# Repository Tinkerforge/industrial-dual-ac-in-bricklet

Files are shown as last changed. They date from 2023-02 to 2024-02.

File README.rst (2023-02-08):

Industrial Dual AC In Bricklet
==============================

**This Bricklet is currently in development.**

This repository contains the firmware source code and the hardware design
files. The documentation generator configs can be found at
https://github.com/Tinkerforge/generators

Repository Content
------------------

software/:
 * examples/: Examples for all supported languages
 * build/: Compiled files
 * src/: Source code of firmware
 * Makefile: Makefile to build project

hardware/:
 * Contains KiCad project files and additionally schematics as PDF

datasheets/:
 * Contains datasheets for sensors and complex ICs that are used

Hardware
--------

The hardware is designed with the open source EDA Suite KiCad
(http://www.kicad.org). Before you are able to open the files,
you have to install the Tinkerforge kicad-libraries
(https://github.com/Tinkerforge/kicad-libraries). You can either clone
them directly in hardware/ or clone them in a separate folder and
symlink them into hardware/
(ln -s kicad_path/kicad-libraries project_path/hardware). After that you
can open the .pro file in hardware/ with KiCad and from there view and
modify the schematics and the PCB layout.

Software
--------

If you want to do your own Brick/Bricklet firmware development we highly
recommend that you use our build environment setup script and read the
tutorial (https://www.tinkerforge.com/en/doc/Tutorials/Tutorial_Build_Environment/Tutorial.html).

To compile the C code we recommend you to install the newest GNU Arm Embedded
Toolchain (https://launchpad.net/gcc-arm-embedded/+download).
You also need to install bricklib2 (https://github.com/Tinkerforge/bricklib2).

You can either clone it directly in software/src/ or clone it in a
separate folder and symlink it into software/src/
(ln -s bricklib_path/bricklib2 project_path/software/src/). Finally make sure to
have CMake installed (http://www.cmake.org/cmake/resources/software.html).

After that you can build the firmware by invoking make in software/.
The firmware (.zbin) can then be found in software/build/ and uploaded
with brickv (click button "Flashing" on start screen).

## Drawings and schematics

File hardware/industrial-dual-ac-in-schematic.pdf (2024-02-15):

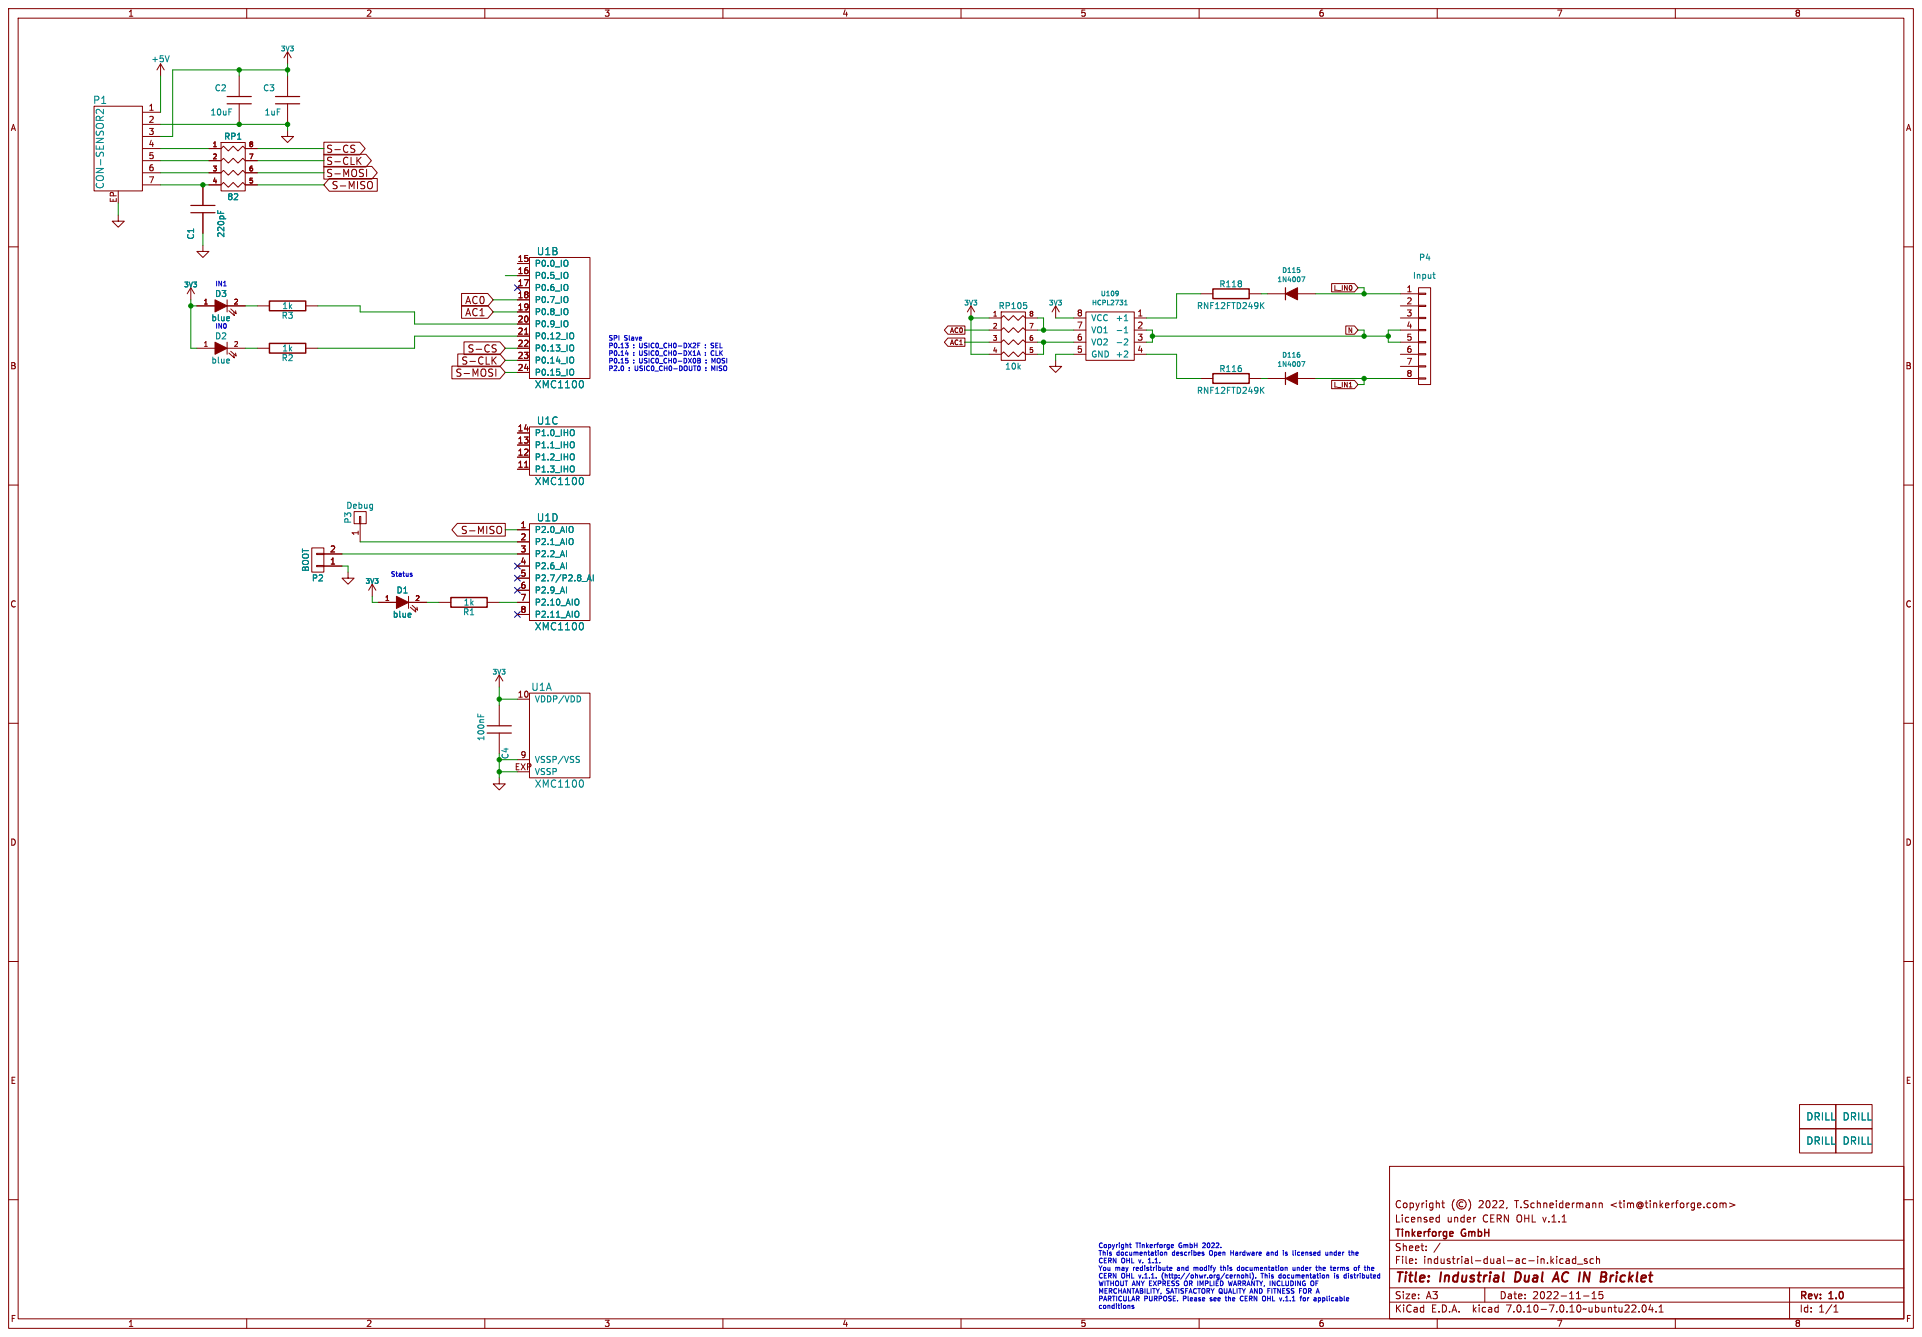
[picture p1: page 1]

Id: 1/1 Title: Industrial Dual AC IN Bricklet File: industrial-dual-ac-in.kicad_sch Sheet: / Tinkerforge GmbH

PARTICULAR PURPOSE. Please see the CERN OHL v.1.1 for applicable
conditions

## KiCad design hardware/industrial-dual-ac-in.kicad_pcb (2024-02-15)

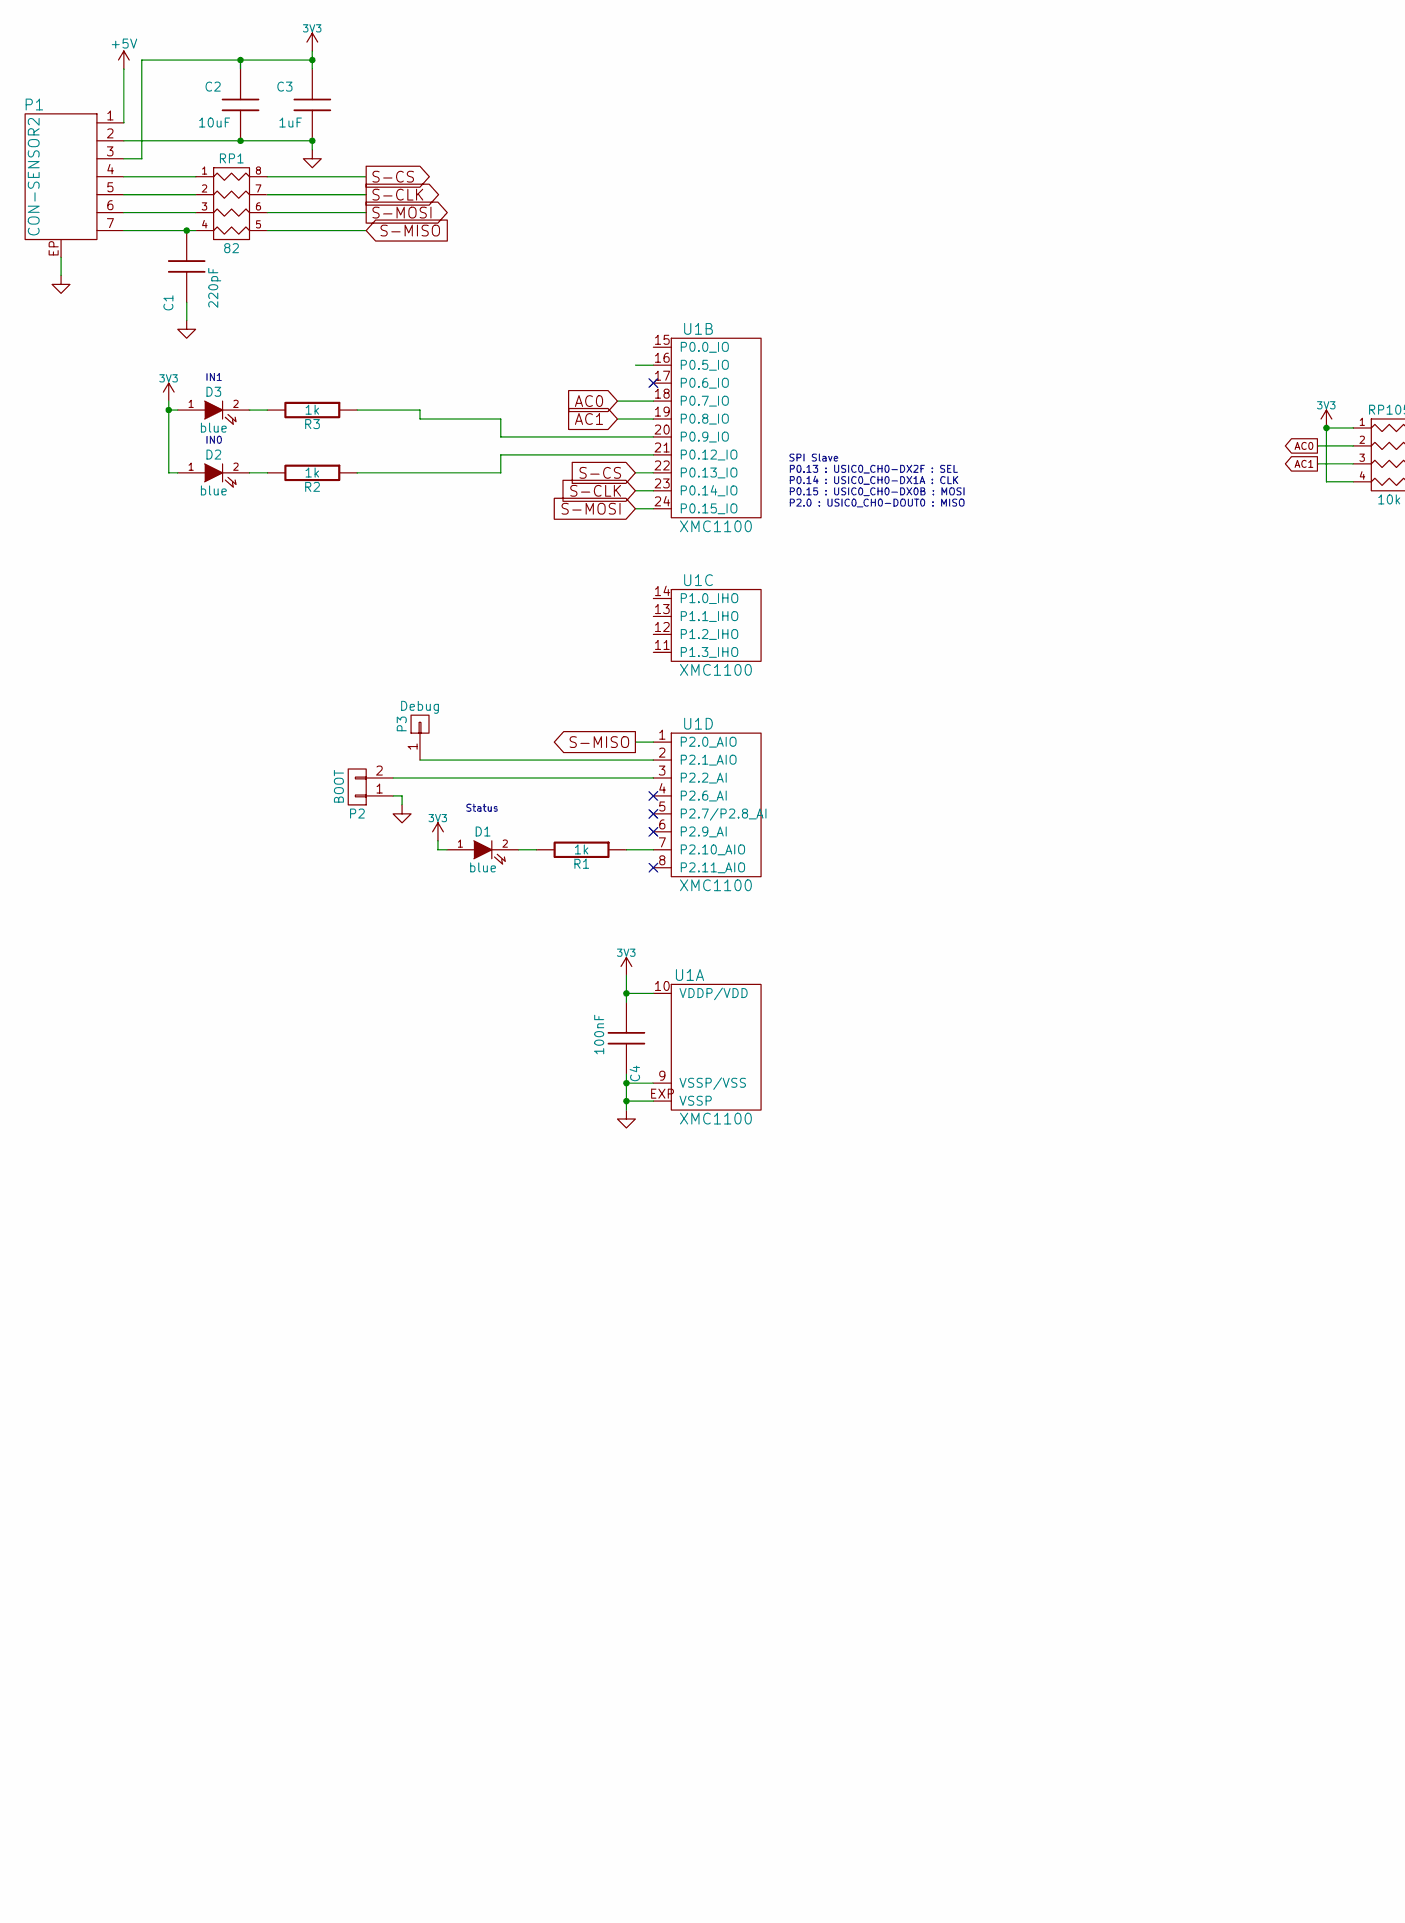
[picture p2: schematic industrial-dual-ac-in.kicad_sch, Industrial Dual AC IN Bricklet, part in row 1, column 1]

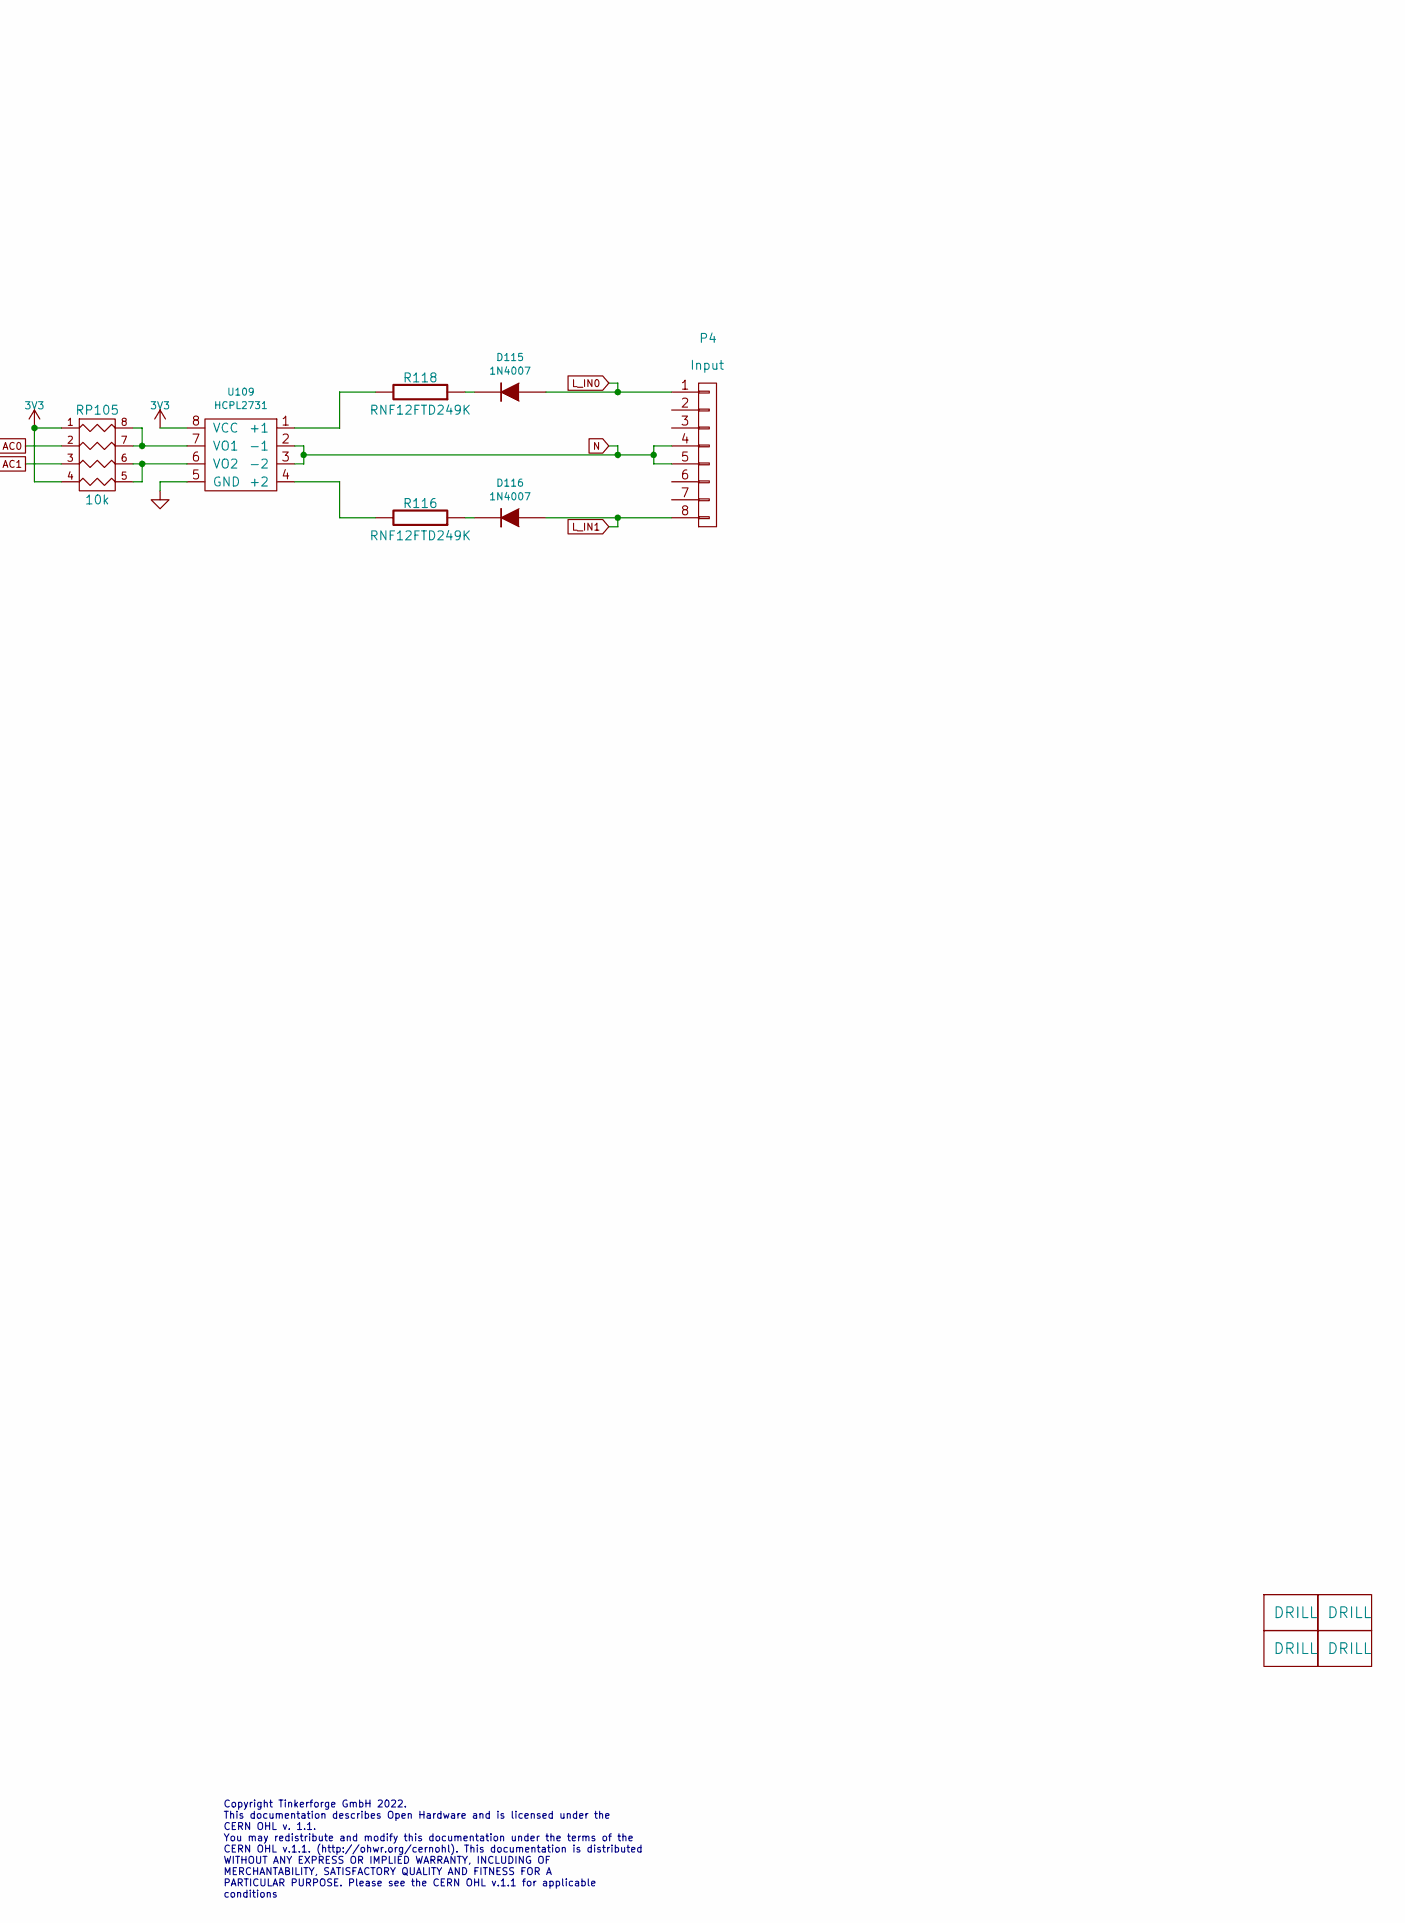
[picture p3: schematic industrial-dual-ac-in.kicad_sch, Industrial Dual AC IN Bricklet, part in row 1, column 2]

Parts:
C1: 220pF; C0402F
C2: 10uF; C0805E
C3: 1uF; C0603F
C4: 100nF; C0603F
D1, D2, D3: blue; D0603E
D115, D116: 1N4007; DO-41
Drill1, Drill2, Drill3, Drill4: DRILL; DRILL_NP
P1: CON-SENSOR2
P2: BOOT; SolderJumper
P3: Debug; DEBUG_PAD
P4: Input; OQ_8P_230V
R1, R2, R3: 1k; R0603F
R116, R118: RNF12FTD249K; RNF12-2
RP1: 82; 4X0402
RP105: 10k; 4X0603
U1: XMC1100; QFN24-4x4mm-0.5mm
U109: HCPL2731; DIP-8

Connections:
3V3: C2.2, C3.2, C4.1, D1.1 (A), D2.1 (A), D3.1 (A), P1.3, RP105.1, RP105.4, U1.10 (VDDP/VDD), U109.8 (VCC)
+5V: P1.1
AC0: RP105.2, U1.18 (P0.7_IO)
AC1: RP105.3, U1.19 (P0.8_IO)
GND: C1.1, C2.1, C3.1, C4.2, P1.2, P1.EP, P2.1, U1.9 (VSSP/VSS), U1.EXP (VSSP), U109.5 (GND)
L_IN0: D115.1 (A), P4.1
L_IN1: D116.1 (A), P4.8
N: P4.4, P4.5, U109.2 (-1), U109.3 (-2)
unnamed: D1.2 (K), R1.2
unnamed: D2.2 (K), R2.2
unnamed: D3.2 (K), R3.2
unnamed: D115.2 (K), R118.1
unnamed: D116.2 (K), R116.1
unnamed: P2.2, U1.3 (P2.2_AI)
unnamed: P3.1, U1.2 (P2.1_AIO)
unnamed: P1.4, RP1.1
unnamed: P1.5, RP1.2
unnamed: P1.6, RP1.3
unnamed: C1.2, P1.7, RP1.4
unnamed: RP105.7 (R2), RP105.8 (R1), U109.7 (VO1)
unnamed: RP105.5 (R4), RP105.6 (R3), U109.6 (VO2)
unnamed: R3.1, U1.20 (P0.9_IO)
unnamed: R2.1, U1.21 (P0.12_IO)
unnamed: R1.1, U1.7 (P2.10_AIO)
unnamed: R118.2, U109.1 (+1)
unnamed: R116.2, U109.4 (+2)
S-CLK: RP1.7 (R2), U1.23 (P0.14_IO)
S-CS: RP1.8 (R1), U1.22 (P0.13_IO)
S-MISO: RP1.5 (R4), U1.1 (P2.0_AIO)
S-MOSI: RP1.6 (R3), U1.24 (P0.15_IO)

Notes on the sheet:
SPI Slave P0.13 : USIC0_CH0-DX2F : SEL P0.14 : USIC0_CH0-DX1A : CLK P0.15 : USIC0_CH0-DX0B : MOSI P2.0 : USIC0_CH0-DOUT0 : MISO
Status
IN0
IN1
Copyright Tinkerforge GmbH 2022. This documentation describes Open Hardware and is licensed under the CERN OHL v. 1.1. You may redistribute and modify this documentation under the terms of the CERN OHL v.1.1. (http://ohwr.org/cernohl). This documentation is distributed WITHOUT ANY EXPRESS OR IMPLIE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

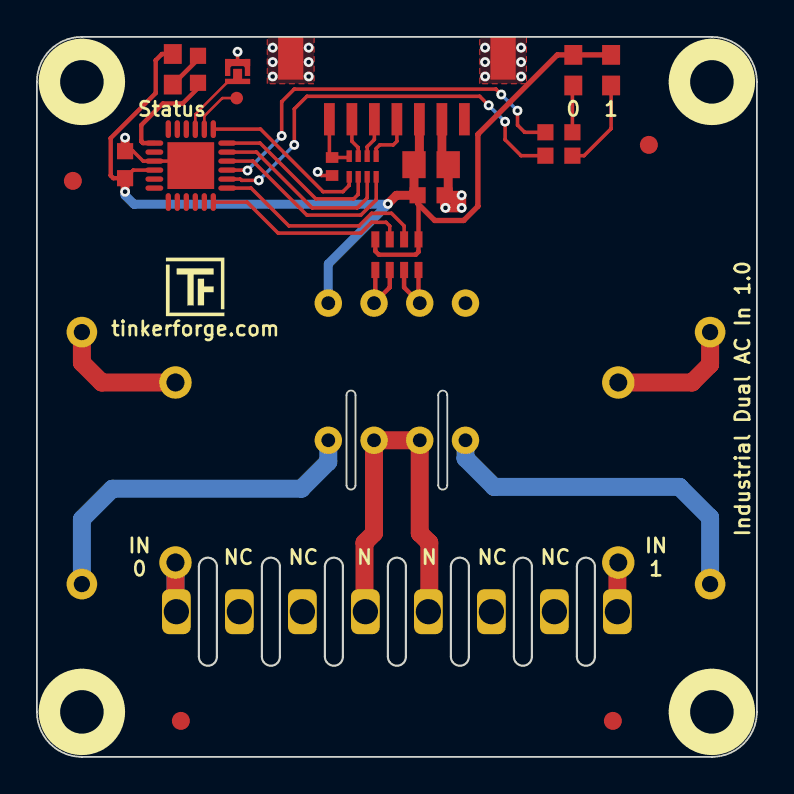
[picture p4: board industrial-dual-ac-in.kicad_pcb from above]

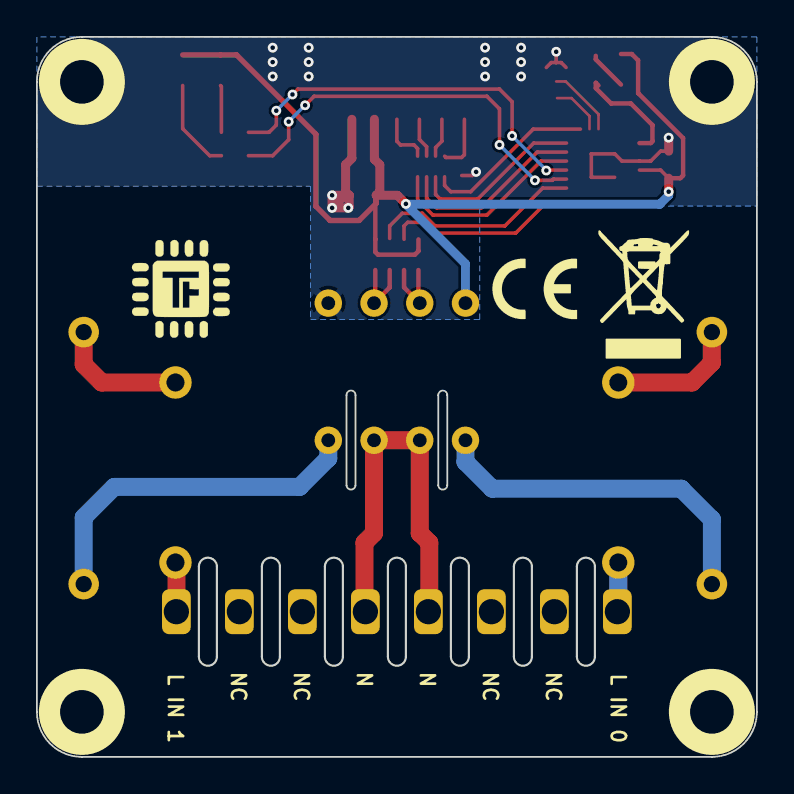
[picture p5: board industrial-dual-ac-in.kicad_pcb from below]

Board: 2 copper layers, 40.0 x 40.0 mm, 32 parts (2 on the bottom side), 29 nets.

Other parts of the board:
Fiducial_Mark: VAL**; Fiducial_Mark
Fiducial_Mark#2, Fiducial_Mark#3, Fiducial_Mark#4: VAL**; Fiducial_Mark
VAL: WEEE_7mm
VAL#2: CE_5mm

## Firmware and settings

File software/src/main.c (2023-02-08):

/* industrial-dual-ac-in-bricklet
 * Copyright (C) 2023 Olaf Lüke <olaf@tinkerfoe.com>
 *
 * main.c: Initialization for Industrial Dual AC In Bricklet
 *
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
 * You should have received a copy of the GNU Lesser General Public
 * License along with this library; if not, write to the
 * Free Software Foundation, Inc., 59 Temple Place - Suite 330,
 * Boston, MA 02111-1307, USA.
 */

#include <stdio.h>
#include <stdbool.h>

#include "configs/config.h"

#include "bricklib2/bootloader/bootloader.h"
#include "bricklib2/hal/system_timer/system_timer.h"
#include "bricklib2/logging/logging.h"
#include "communication.h"

#include "ac_in.h"

int main(void) {
	logging_init();
	logd("Start Industrial Dual AC In Bricklet\n\r");

	communication_init();
	ac_in_init();

	while(true) {
		bootloader_tick();
		communication_tick();
		ac_in_tick();
	}
}

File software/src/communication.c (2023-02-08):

/* industrial-dual-ac-in-bricklet
 * Copyright (C) 2023 Olaf Lüke <olaf@tinkerfoe.com>
 *
 * communication.c: TFP protocol message handling
 *
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
 * You should have received a copy of the GNU Lesser General Public
 * License along with this library; if not, write to the
 * Free Software Foundation, Inc., 59 Temple Place - Suite 330,
 * Boston, MA 02111-1307, USA.
 */

#include "communication.h"

#include "bricklib2/hal/system_timer/system_timer.h"
#include "bricklib2/utility/communication_callback.h"
#include "bricklib2/protocols/tfp/tfp.h"

#include "ac_in.h"

BootloaderHandleMessageResponse handle_message(const void *message, void *response) {
	switch(tfp_get_fid_from_message(message)) {
		case FID_GET_VALUE: return get_value(message, response);
		case FID_SET_VALUE_CALLBACK_CONFIGURATION: return set_value_callback_configuration(message);
		case FID_GET_VALUE_CALLBACK_CONFIGURATION: return get_value_callback_configuration(message, response);
		case FID_SET_ALL_VALUE_CALLBACK_CONFIGURATION: return set_all_value_callback_configuration(message);
		case FID_GET_ALL_VALUE_CALLBACK_CONFIGURATION: return get_all_value_callback_configuration(message, response);
		case FID_SET_CHANNEL_LED_CONFIG: return set_channel_led_config(message);
		case FID_GET_CHANNEL_LED_CONFIG: return get_channel_led_config(message, response);
		default: return HANDLE_MESSAGE_RESPONSE_NOT_SUPPORTED;
	}
}


BootloaderHandleMessageResponse get_value(const GetValue *data, GetValue_Response *response) {
	response->header.length = sizeof(GetValue_Response);
	response->value[0]      = ac_in.value[0] | (ac_in.value[1] << 1);

	return HANDLE_MESSAGE_RESPONSE_NEW_MESSAGE;
}

BootloaderHandleMessageResponse set_value_callback_configuration(const SetValueCallbackConfiguration *data) {
	if(data->channel >= AC_IN_CHANNEL_NUM) {
		return HANDLE_MESSAGE_RESPONSE_INVALID_PARAMETER;
	}	

	ac_in.cb_value_period[data->channel]        = data->period;
	ac_in.cb_value_has_to_change[data->channel] = data->value_has_to_change;
	ac_in.cb_value_last_value[data->channel]    = ac_in.value[data->channel];
	ac_in.cb_value_last_time[data->channel]     = 0;

	return HANDLE_MESSAGE_RESPONSE_EMPTY;
}

BootloaderHandleMessageResponse get_value_callback_configuration(const GetValueCallbackConfiguration *data, GetValueCallbackConfiguration_Response *response) {
	if(data->channel >= AC_IN_CHANNEL_NUM) {
		return HANDLE_MESSAGE_RESPONSE_INVALID_PARAMETER;
	}

	response->header.length = sizeof(GetValueCallbackConfiguration_Response);
	response->period              = ac_in.cb_value_period[data->channel];
	response->value_has_to_change = ac_in.cb_value_has_to_change[data->channel];

	return HANDLE_MESSAGE_RESPONSE_NEW_MESSAGE;
}

BootloaderHandleMessageResponse set_all_value_callback_configuration(const SetAllValueCallbackConfiguration *data) {
	ac_in.cb_all_period        = data->period;
	ac_in.cb_all_has_to_change = data->value_has_to_change;
	ac_in.cb_all_last_value    = ac_in.value[0] | (ac_in.value[1] << 1);
	ac_in.cb_all_last_time     = 0;

	return HANDLE_MESSAGE_RESPONSE_EMPTY;
}

BootloaderHandleMessageResponse get_all_value_callback_configuration(const GetAllValueCallbackConfiguration *data, GetAllValueCallbackConfiguration_Response *response) {
	response->header.length       = sizeof(GetAllValueCallbackConfiguration_Response);
	response->period              = ac_in.cb_all_period;
	response->value_has_to_change = ac_in.cb_all_has_to_change;

	return HANDLE_MESSAGE_RESPONSE_NEW_MESSAGE;
}

BootloaderHandleMessageResponse set_channel_led_config(const SetChannelLEDConfig *data) {
	if(data->channel >= AC_IN_CHANNEL_NUM) {
		return HANDLE_MESSAGE_RESPONSE_INVALID_PARAMETER;
	}

	if(data->config > INDUSTRIAL_DUAL_AC_IN_CHANNEL_LED_CONFIG_SHOW_CHANNEL_STATUS) {
		return HANDLE_MESSAGE_RESPONSE_INVALID_PARAMETER;
	}

	ac_in.led_flicker_state[data->channel].config = data->config;
	if(data->config == INDUSTRIAL_DUAL_AC_IN_CHANNEL_LED_CONFIG_OFF) {
		XMC_GPIO_SetOutputHigh(ac_in_led[data->channel].port, ac_in_led[data->channel].pin);
	} else if(data->config == INDUSTRIAL_DUAL_AC_IN_CHANNEL_LED_CONFIG_ON) {
		XMC_GPIO_SetOutputLow(ac_in_led[data->channel].port, ac_in_led[data->channel].pin);
	}

	return HANDLE_MESSAGE_RESPONSE_EMPTY;
}

BootloaderHandleMessageResponse get_channel_led_config(const GetChannelLEDConfig *data, GetChannelLEDConfig_Response *response) {
	if(data->channel >= AC_IN_CHANNEL_NUM) {
		return HANDLE_MESSAGE_RESPONSE_INVALID_PARAMETER;
	}

	response->header.length = sizeof(GetChannelLEDConfig_Response);
	response->config        = ac_in.led_flicker_state[data->channel].config;

	return HANDLE_MESSAGE_RESPONSE_NEW_MESSAGE;
}




bool handle_value_callback_channel(const uint8_t channel) {
	static bool is_buffered[AC_IN_CHANNEL_NUM] = {false, false};
	static Value_Callback cb[AC_IN_CHANNEL_NUM];

	if(!is_buffered[channel]) {
		if((ac_in.cb_value_period[channel] == 0) || !system_timer_is_time_elapsed_ms(ac_in.cb_value_last_time[channel], ac_in.cb_value_period[channel])) {
			return false;
		}

		const bool changed = ac_in.cb_value_last_value[channel] != ac_in.value[channel];
		if(ac_in.cb_value_has_to_change[channel] && !changed) {
			return false;
		}

		tfp_make_default_header(&cb[channel].header, bootloader_get_uid(), sizeof(Value_Callback), FID_CALLBACK_VALUE);
		cb[channel].channel = channel;
		cb[channel].changed = changed;
		cb[channel].value   = ac_in.value[channel];

		ac_in.cb_value_last_value[channel] = ac_in.value[channel];
		ac_in.cb_value_last_time[channel]  = system_timer_get_ms();
	}

	if(bootloader_spitfp_is_send_possible(&bootloader_status.st)) {
		bootloader_spitfp_send_ack_and_message(&bootloader_status, (uint8_t*)&cb[channel], sizeof(Value_Callback));
		is_buffered[channel] = false;
		return true;
	} else {
		is_buffered[channel] = true;
	}

	return false;
}

bool handle_value_callback(void) {
	static uint8_t channel = 0;

	// Go through all channels round robin until one of the channels has something to send
	for(uint8_t i = 0; i < AC_IN_CHANNEL_NUM; i++) {
		bool ret = handle_value_callback_channel(channel);
		channel = (channel+1) % AC_IN_CHANNEL_NUM;
		if(ret) {
			return true;
		}
	}

	return false;
}
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

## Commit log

2022-11-16 ready for prototype
    [industrial-dual-ac-in.kicad_pcb, industrial-dual-ac-in.kicad_sch]
2022-11-16 more clearance for screwholes
    [industrial-dual-ac-in.kicad_pcb, industrial-dual-ac-in.kicad_sch]
2022-11-16 switched debug an boot pin
    [industrial-dual-ac-in.kicad_pcb, industrial-dual-ac-in.kicad_sch]
2022-11-28 added fiducial mark
    [industrial-dual-ac-in.kicad_pcb]
2022-11-28 updated mounting holes
    [industrial-dual-ac-in.kicad_pcb, industrial-dual-ac-in.kicad_sch]
2023-02-08 Add Industrial Dual AC In Bricklet firmware
    [cmake_config_custom.txt]
2024-02-15 add schematic, update project
    [industrial-dual-ac-in.kicad_pcb, industrial-dual-ac-in.kicad_sch]

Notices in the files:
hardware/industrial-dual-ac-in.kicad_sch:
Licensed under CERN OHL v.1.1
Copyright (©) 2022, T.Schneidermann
